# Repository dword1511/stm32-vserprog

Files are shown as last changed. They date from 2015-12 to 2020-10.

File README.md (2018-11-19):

# stm32-vserprog:
## flashrom serprog programmer based on STM32 MCU & USB CDC protocol.
**This project deprecates previous [`serprog-stm32vcp`](https://github.com/dword1511/serprog-stm32vcp) project,
  which uses STMicro's proprietary firmware library. Most functions are the same.**

* * *
### Features
* Fully open-source: now with [`libopencm3`](https://github.com/libopencm3/libopencm3) instead of STMicro's proprietary firmware library.
* Affordable and simple hardware:
  * An _STM32F103C8T6_ MCU, an 8MHz crystal, a 3.3V _1117_ LDO, some _0805_ capacitors, resistors and LEDs
    along with dedicated PCB available on OSH Park ([V2](https://oshpark.com/shared_projects/08Rj6sSm)
    or [V3](https://oshpark.com/shared_projects/vKn08YZG))
  * Or some general-purpose _STM32_ development boards,
  just add a new header file under "boards" folder to assign correct GPIO for USB D+ pull-up (_STM32F1_ only) and LEDs.
  * Hardware USB 2.0 Full-Speed and efficient virtual COM port with USB CDC protocol operates at any baud rates,
  eliminates the need of USB-to-UART bridges and the headache that comes with them.
  * **Ironically, you will still have to buy or borrow a USB-to-UART bridge (not RS-232 but TTL level) to program the programmer itself,**
  unless you are using an _STM32F0x2_ device (which has USB ISP capability) or boards with embedded _ST-Link_ (see @FabianInostroza's fork).
* Hardware full-duplex SPI with DMA, multiple clock speeds available (default at the one closest to but under 10MHz), _e.g._ on STM32F103 targets:
  * 36MHz
  * 18MHz
  * 9MHz *(Default)*
  * 4.5MHz
  * 2.25MHz
  * 1.125MHz
  * 562.5kHz
  * 281.25kHz
* 2 status LEDs (controlled with 1 GPIO):
  * Busy is lit during operation (inverse for boards with only one LED).
  * Different operations cause different patterns of blinking:
  mostly busy = reading, both on = writing, flashing alternatively = erasing.
  * Busy blinks alone if a hard fault or NMI is detected. Please unplug and replug the programmer.
  If the situation persists, please consider [opening a new ticket](https://github.com/dword1511/stm32-vserprog/issues).
* `flashrom` "serprog" protocol:
  * Operates on all major platforms (see [`flashrom` wiki](http://www.flashrom.org/Flashrom)).
  * Driver-free on Linux. On Windows may require ST's VCP driver
  (or just hack the `.inf` file of other CDC drivers, not confirmed).
* Firmware is interrupt-free except for low-level USB handling -- robust, easy to debug and modify.
* Fast:
  * Read speed up to 850KiB/s @ 36MHz SPI operation.
  * Dumps an _EN25Q64_ in 11 seconds and programs in 85 seconds (including `flashrom`'s calibration time).
  * Way faster than many commercial _CH341_-based USB programmers, especially for reading.
* Supports 25 and 26 series SPI flash chips.
  **45 series flash chips have different pinouts. Thus for the V2 PCB mentioned above, you will need an adapter.**

* * *
### Installation
1. Install `stm32flash` and the `gcc-arm-none-eabi` toolchain.

  On Debian, simply do the following:

   ```bash
   sudo apt-get install stm32flash gcc-arm-none-eabi
   ```
  
  NOTE: some systems may require installing `newlib` (_e.g._ `libnewlib-arm-none-eabi`) manually. See [#27](https://github.com/dword1511/stm32-vserprog/issues/27).

1. Clone and compile.

  Simply type (change the board name accordingly, for details see the header of the `Makefile` or just type `make`):

   ```bash
   git clone --recurse-submodules https://github.com/dword1511/stm32-vserprog.git
   make BOARD=stm32-vserprog-v2
   ```
1. Program.

  Connect the USB-to-UART bridge to your computer first. Then connect _TXD_ and _RXD_ lines to your _STM32_ board with wires.
  On V2 or V3 boards mentioned above, connect _BOOT0_ (labeled _BT0_ on boards) to the 3.3V output of the USB-to-UART bridge.
  For other boards, find the _BOOT0_ jumper or ISP switch, put it into high or enabled.
  On some boards, you will also need to ensure _BOOT1_ is pulled low.
  Then, connect your _STM32_ board to your computer via USB to power it up.
  Finally, type:

   ```bash
   make BOARD=stm32-vserprog-v2 flash-uart
   ```
1. Done!

  Throw the USB-to-UART bridge away and enjoy.
  Do not forget to pull _BOOT0_ low before resetting or replugging the board.

* * *
### Usage
The following assumes Linux platform, and that the programmer appears as `/dev/ttyACM0`.

1. To read a flash chip:
  * Connect a 25 type SPI Flash to the board's DIP-8 slot or according to the schematics.
  * Connect your board to your PC via USB.
  * Type:

   ```bash
   flashrom -p serprog:dev=/dev/ttyACM0:4000000 -r file-to-save.bin
   ```
  * Sometimes `flashrom` will ask you to choose a chip, add something like:

   ```bash
   -c SST25VF040B
   ```
   This is because sometimes different devices with distinct timing requirements can only be distinguished by the device code,
   however currently `flashrom` will not read it as it is not returned by the `RDID` command.
1. To erase a flash chip:
  * Erase is automatically done during writing. However, if you simply want an empty chip, you will need to erase manually.
  * Type:

   ```bash
   flashrom -p serprog:dev=/dev/ttyACM0:4000000 -E
   ```
  * For certain chips like _MX25L6445E_, the first pass could fail with some old `flashrom` version,
    but if you try a second pass, everything will be alright. Seems that the first block needs more delay to be erased.
  * Flash contents are verified to be empty automatically.
  * The whole process can take a few minutes.
1. To write a flash chip:
  * Type:

   ```bash
   flashrom -p serprog:dev=/dev/ttyACM0:4000000 -w file-to-load.bin
   ```
  * Flash chips are checked and blocks that are not empty are automatically erased.
  * Images are verified after writing automatically.
  * The whole process can take a few minutes.

* * *
### Problems?
1. If you encountered something like "`Error: Cannot open serial port: Device or resource busy`", please try to stop or remove `ModemManager`.
1. Check your wirings and `flashrom` version. Do not forget to power the flash chip itself if operating on a breadboard or prototype board.
1. If you are sure it is caused by bugs in the programmer's firmware,
   please [open a new ticket](https://github.com/dword1511/stm32-vserprog/issues) and provide details,
   _e.g._ the board you are using and `flashrom`'s output. I appreciate your feedback.

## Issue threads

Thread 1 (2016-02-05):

Which stm32 should I use

relax79, 2016-02-05:
Hello, i am work notebook repair bussiness and i am work with bios most time. I have a genius g540 programmer and is so slow. I am decide to build your programmer but i see first this page"https://github.com/dword1511/serprog-stm32vcp"  and you say STM32F103C8T6 48pin in readme but mcu is different in the schematic pdf STM32F103Rxxx an i am buy STM32F103R8T6, it is 64pin. I saw later this version of the programmer but same confusing happen to me again , you say STM32F103C8T6 but in the schematic mcu is STM32F103C(B)T6 . I am good electronic skill but i do not understand modern digital mcu's so much :) . I am download also prebuilt binaries from here "http://dword1511.info/dword/projects/serprog-stm32vcp/prebuilt/" My question is can i use STM32F103R8T6 and if i use which hex or bin  and schematic correct, and also missing in the first schematic xtal (i know 8mhz and 2x15 or 22pf) and a lot of parts value, correct uart pin points  . If i not use then which mcu can i buy ?
"http://www.direnc.net/STM32F103CBT6-MCU-32BIT-CORTEX-M3-72MHZ-LQFP-48,PR-23142.html"
"http://www.direnc.net/STM32F103C8T6-MCU-32BIT-CORTEX-M3-72MHZ-LQFP-48,PR-23141.html"
"http://www.direnc.net/STM32F103C8T6-Mini-Development-Board-ARDUINO,PR-22302.html"
"http://www.direnc.net/ARM-Cortex-M3-STM32F103C8T6-STM32-development-board,PR-15818.html"
I am so sorry for my English, i know messed up the spech. Thanks.

dword1511, 2016-02-05:
Thanks for pointing the error out, I did not notice it for years!
The difference between STM32F103Cxxx is just different amount of Flash and RAM available. Since STM32F103C8T6 has the least amount, firmware built for it should also run on others.
If you have a board at hand, please send the schematics to me so I can write the board.h for it and compile the firmware you will need.

relax79, 2016-02-05:
I am not have a board, only have STM32F103R8T6 mcu "http://urun.gittigidiyor.com/ev-elektronigi/st-stm32f103r8t6-200855568" (I just bought a new). If you say buy a new mcu or board please chose for me in the links in my previus message then i am bought new one, not problem if it is working properly. Thanks,regards.

relax79, 2016-02-05:
I am confuse first place because you say "just with minor modifications in the source code to assign correct GPIO for USB D+ pullup and LEDs." I thought editing requires different mcu's.like c8t6, cbt6, r8t6.

dword1511, 2016-02-05:
If you do not have a board and need one, then just go for the cheapest STM32F103 board. Any MCU in the series will work without problem.

If you do have the board to solder the MCU you have just bought, please refer to https://github.com/dword1511/stm32-vserprog/blob/master/pcb/v2/sch.pdf for correct connection. R2/R4 in this schematic is 20ohm or so, PB2 and BOOT0 just need some pull down, C4/C5 are 15 or 22pF, C1/C2/C3 0.1uF, C6/C9 10uF, C7/C10 0.1uF. R6 is a fuse. LED can be omitted if you wish. Then just use "make BOARD=stm32-vserprog-v2" to compile the firmware.

STM32F103 series are pin-to-pin compatible when the package is the same. When package is not same, the pinout is different, but firmware sees no difference in terms of pin name.

relax79, 2016-02-05:
I have to decide which one to buy then i am prepare everything, If i happen some trouble i will let you know.I am really thanks your kind support,answers and effort to build this good project.

Closed 2016-06-09.

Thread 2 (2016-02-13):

Compile error when building for stm32-tiny042-v1

graugans, 2016-02-13:
There is an issue when building for stm32-tiny042-v1 or any stm32f0x boards

```
$ make BOARD=stm32-tiny042-v1
ln -sfT "boards/stm32-tiny042-v1.h" board.h
arm-none-eabi-gcc -O3 -Wall -g -fno-common -ffunction-sections -fdata-sections -DSTM32F0 -mthumb -mcpu=cortex-m0 -msoft-float -Ilibopencm3/include/  -c vserprog.c -o vserprog.o
In file included from vserprog.c:14:0:
vserprog.c: In function 'handle_command':
spi.h:11:42: error: 'GPIO_SPI1_NSS' undeclared (first use in this function)
 #define SPI_SELECT()   gpio_clear(GPIOA, GPIO_SPI1_NSS)
                                          ^
vserprog.c:193:7: note: in expansion of macro 'SPI_SELECT'
       SPI_SELECT();
       ^
spi.h:11:42: note: each undeclared identifier is reported only once for each function it appears in
 #define SPI_SELECT()   gpio_clear(GPIOA, GPIO_SPI1_NSS)
```

dword1511, 2016-02-13:
Hi, support for STM32F0x2 is not completed yet. I will try to finish it when I have time.

graugans, 2016-02-13:
Thx, this would be really cool

dword1511, 2016-03-03:
Implemented and tested, ready for use. STM32F0 version seems to be ~70% slower than STM32F1 version. Whether it is due to clock or configuration is still unknown.

Closed 2016-03-03.

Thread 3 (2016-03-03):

Write HAL to handle different MCU

dword1511, 2016-03-03:
Currently there is a lot of macros everywhere. Need to abstract things up and put them together.

Kurnihil, 2016-03-11:
After this rewriting it would be possible to use your library (program?) with the NXP board "FRDM-KE06Z" (MKE06Z128VLK4 MCU)..?

dword1511, 2016-03-11:
I do not have the board, and it seems libopencm3 currently does not support this MCU, so I think it will not.

Closed 2017-05-23.

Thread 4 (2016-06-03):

LPC/FWH support?

Split7fire, 2016-06-03:
On old project page (https://github.com/dword1511/serprog-stm32vcp) it is said that "Support LPC / FWH flash via parallel programming. [WIP]" but that about stm32-vserprog? Does it support LPC/FWH at hte moment?

dword1511, 2016-06-03:
No. In the old version it was marked as work in progress (WIP) but I never had time to finish it.

Split7fire, 2016-06-03:
Thanks for fast response,
so, LPC/FWH support in that project is working anyway? (read/write)

dword1511, 2016-06-03:
Unfortunately it is not.

Split7fire, 2016-06-03:
ok, thanks for clarification, I think this issue can be closed now.

swiftgeek, 2023-01-15:
Relevant fork/derivative work:
https://github.com/wosk/stm32-vserprog-lpc

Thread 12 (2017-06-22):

Native 4-byte addressing

eswierk, 2017-06-22:
It would be nice to support larger-capacity SPI NOR flash chips like W25256FV and N25Q256A that require 4-byte addressing.

dword1511, 2017-06-22:
`flashrom` currently does not support 4-byte addressing as far as I known. There were [patches](https://mail.coreboot.org/pipermail/flashrom/2015-January/013168.html) proposed but they are probably unmerged.

eswierk, 2017-06-22:
I've managed to get a flashrom with those patches working well enough to program an N25Q256A using an FT232H module, but it's awfully slow.

https://github.com/skyportsystems/flashrom/commits/master

eswierk, 2017-07-03:
It is possible to program N25Q/MT25QL chips larger than 16 MB with the existing flashrom serprog, using only commands with 3-byte addresses, plus the extended address register for the 4th byte. See https://github.com/skyportsystems/flashrom/commit/db3ca240 for an example.

Other chips may require native 4-byte addressing, but I haven't encountered them so far.

dword1511, 2017-07-03:
With a proper patch for `flashrom`, any serprog should be able to handle 4-byte addressing. It is merely an SPI-to-USB bridge. It has no knowledge about the protocol. The commands with address parameters in serprog protocol are for parallel flash chips. The only limitation for serprog with SPI is that the size of each transaction (command or data) must be under 16MB.

eswierk, 2017-07-03:
Ah! Thanks for the clarification. I confirmed that programming an M25QL256 with flashrom serprog works with direct 4-byte address commands. See https://github.com/skyportsystems/flashrom/commit/d30fcd40 .

Closed 2017-07-03.

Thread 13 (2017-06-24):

Build is failing on xenial

Ntemis, 2017-06-24:
make --directory=lib/stm32/f1 SRCLIBDIR="/media/demetris/c4487cfd-d71a-441b-b83d-23d8ce19475d/stm32-vserprog/libopencm3/lib"
make[3]: Entering directory '/media/demetris/c4487cfd-d71a-441b-b83d-23d8ce19475d/stm32-vserprog/libopencm3/lib/stm32/f1'
  CC      i2c_common_v1.c
arm-none-eabi-gcc -Os -Wall -Wextra -Wimplicit-function-declaration -Wredundant-decls -Wmissing-prototypes -Wstrict-prototypes -Wundef -Wshadow -I../../../include -fno-common -mcpu=cortex-m3  -mthumb -Wstrict-prototypes -ffunction-sections -fdata-sections -MD -DSTM32F1 -ggdb3 -O3 -Wall -g -fno-common -ffunction-sections -fdata-sections -funit-at-a-time -fgcse-sm -fgcse-las -fgcse-after-reload -funswitch-loops -DSTM32F1 -mthumb -mcpu=cortex-m3 -msoft-float -mfix-cortex-m3-ldrd -Ilibopencm3/include/  -o i2c_common_v1.o -c ../common/i2c_common_v1.c
../common/i2c_common_v1.c: In function 'i2c_write7_v1':
../common/i2c_common_v1.c:485:2: error: 'for' loop initial declarations are only allowed in C99 or C11 mode
  for (size_t i = 0; i < n; i++) {
  ^
../common/i2c_common_v1.c:485:2: note: use option -std=c99, -std=gnu99, -std=c11 or -std=gnu11 to compile your code
../common/i2c_common_v1.c: In function 'i2c_read7_v1':
../common/i2c_common_v1.c:507:2: error: 'for' loop initial declarations are only allowed in C99 or C11 mode
  for (size_t i = 0; i < n; ++i) {
  ^
../../Makefile.include:44: recipe for target 'i2c_common_v1.o' failed
make[3]: *** [i2c_common_v1.o] Error 1
make[3]: Leaving directory '/media/demetris/c4487cfd-d71a-441b-b83d-23d8ce19475d/stm32-vserprog/libopencm3/lib/stm32/f1'
Makefile:63: recipe for target 'lib/stm32/f1' failed
make[2]: *** [lib/stm32/f1] Error 2
make[2]: Leaving directory '/media/demetris/c4487cfd-d71a-441b-b83d-23d8ce19475d/stm32-vserprog/libopencm3'
Makefile:102: recipe for target 'libopencm3/lib/libopencm3_stm32f1.a' failed
make[1]: *** [libopencm3/lib/libopencm3_stm32f1.a] Error 2
make[1]: Leaving directory '/media/demetris/c4487cfd-d71a-441b-b83d-23d8ce19475d/stm32-vserprog'
Makefile:51: recipe for target 'all' failed
make: *** [all] Error 2

dword1511, 2017-06-25:
Please try `make EXTRA_CFLAGS="-std=gnu99"`. Also please post the output of `arm-none-eabi-gcc -v`.

dword1511, 2017-06-26:
Confirmed that `make EXTRA_CFLAGS="-std=gnu99"` worked on Xenial. Now included in Makefile.

Closed 2017-06-26.

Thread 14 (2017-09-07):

C1 V3 board value?

raoul170, 2017-09-07:
what value has c1 ?

dword1511, 2017-09-07:
C1 is 0.1uF.

When I have time I will rectify all the schematics.

raoul170, 2017-09-07:
is it possible you make a release file? Want to program bin or hex via STlink , I cannot work with the makerfile thigs

Droid-MAX, 2019-04-21:
@raoul170 Look there: [STM32闪存编程器.zip](https://pan.droidmax.top/?/Programs/STM32%E9%97%AA%E5%AD%98%E7%BC%96%E7%A8%8B%E5%99%A8.zip)

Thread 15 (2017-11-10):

~~x�~hellowor problem

atesonur, 2017-11-10:
Thank you so much for your code, it helped me a lot. But I have a problem. When I start up my stm32f103 device and try to read 14 bytes from virtual port by using usb_getc(),  First 6 bytes are  always like ~~x�~ these. I understood that they stay there when I start up system and if I write 14 bytes,  I can only write first 8 bytes The first 6 bytes already occupied by these characters.
Do you have any suggestion and thanks a lot for the code you support.

dword1511, 2017-11-10:
Check whether there are other programs accessing the serial port.

atesonur, 2017-11-10:
Thank you so much for your time. None of my programs are using serial port and even I restarted my computer just in case. I am using linux and after restart,  I got these:

master@Lenovo:~/Desktop$ sudo python echo2.py helloworldonur
~~x�~hellowor
master@Lenovo:~/Desktop$ sudo python echo2.py helloworldonur
ldonurhellowor

Thank you so much.

dword1511, 2017-11-10:
I do not know what you are using. Can you use `minicom`?

Make sure `ModemManager` is not running.

atesonur, 2017-11-11:
Thank you so much. I used minicom. It is same but i used a similar command handler like you do. It works fine. Thanks a lot for your time.

dword1511, 2017-11-11:
Without the exact description of your code and what you are doing, I cannot help you. If it is a project of your own, please use email rather than issues. Thanks!

Closed 2017-11-11.

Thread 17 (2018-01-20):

Can build in window 7 ?

budiliauw87, 2018-01-20:
Hello dword, I'm very glad found your git from forum stm32ardunio.. i try complie in windows but failed.

Closed 2018-01-23.

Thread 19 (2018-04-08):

驱动这块会不会有问题？

Droid-MAX, 2018-04-08:
从打板到元器件采购到组装焊接再到编译烧录程序这整个流程都没有问题，但在Windows10/Linux系统的主机上使用时却无法正常识别出来，指示灯正常工作
PS：第一次插上去时在设备管理器中有个未知设备一闪而过，之后一点反应都没有
不知道是不是因为当时误把22千欧(片上标识为223)的贴片电阻用在R2和R4的缘故，不过现在已经换回来了
除此之外该排查的地方也都排查过了，仍未确定问题所在。。。

dword1511, 2018-04-10:
USB 1.5K 的上拉没有问题吗？Linux 下的 dmesg 看一下？确认 STM32 是原装正片？

Droid-MAX, 2018-04-10:
电阻片上标识为152，还没有量过

Droid-MAX, 2019-01-08:
问题已解决，原因在于按照README的操作步骤编译得来的是V2版本的固件，烧录到V3版本的板子里去的话是绝对有问题的，今天心血来潮又重新捡起了板子，修改了编译参数得到了V3版本固件，重新烧录到编程器当中，最终如愿以偿，非常感谢大佬的这个非常优秀的项目！

Closed 2019-01-08.

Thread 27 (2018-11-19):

Cosmic/18.04: Had to install libnewlib-arm-none-eabi to resolve stdint.h not found error.

kamilion, 2018-11-19:
Went and got stm32flash and gcc-arm-none-eabi on cosmic, but build failed. Googling indicated the package 'libnewlib-arm-none-eabi' was missing. Installed it. Build successful.

dword1511, 2018-11-19:
Thanks for the feedback. On most of the systems `gcc-arm-none-eabi` should depend on `newlib`. I will add a heads-up in the README.

Closed 2018-11-19.

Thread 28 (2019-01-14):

How to use udev rules to make a symbol link of /dev/ttyACM<N>

KalelCooper, 2019-01-14:
First  let's see how 'Black Magic Probe' did this:
```
$ udevadm info --attribute-walk /dev/ttyACM0
  looking at device '/devices/pci0000:00/0000:00:1a.1/usb4/4-1/4-1:1.0/tty/ttyACM0':
    KERNEL=="ttyACM0"
    SUBSYSTEM=="tty"
    DRIVER==""

  looking at parent device '/devices/pci0000:00/0000:00:1a.1/usb4/4-1/4-1:1.0':
    KERNELS=="4-1:1.0"
    SUBSYSTEMS=="usb"
    DRIVERS=="cdc_acm"
    ...
    ATTRS{interface}=="Black Magic GDB Server"
```
And it's udev rules like this:
```
DRIVERS=="cdc_acm", ATTRS{interface}=="Black Magic GDB Server", SYMLINK+="bmp_gdb"
DRIVERS=="cdc_acm", ATTRS{interface}=="Black Magic UART Port", SYMLINK+="bmp_uart"
```

But stm32-vserprog has no such thing like ATTRS{interface} :
```
$ udevadm info --attribute-walk /dev/ttyACM2
  looking at device '/devices/pci0000:00/0000:00:1d.2/usb8/8-2/8-2:1.0/tty/ttyACM2':
    KERNEL=="ttyACM2"
    SUBSYSTEM=="tty"
    DRIVER==""
  looking at parent device '/devices/pci0000:00/0000:00:1d.2/usb8/8-2/8-2:1.0':
    KERNELS=="8-2:1.0"
    SUBSYSTEMS=="usb"
    DRIVERS=="cdc_acm"
    ...
    ATTRS{supports_autosuspend}=="1"
```
So, how to add "ATTRS{interface}" to stm32-vserprog ?

dword1511, 2019-01-18:
Use `ATTR{ID_MODEL}=="STM32_virtual_serprog_for_flashrom"`. I did not specify strings for individual interfaces.

Closed 2020-06-11.

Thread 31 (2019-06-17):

How to connect a 25 type SPI Flash to the board's DIP-8 slot ? where can find the schematics?

liaolunhui, 2019-06-17:
I am new to MCU.
Can anyone show me schematics that connect STM32F103C8T6 and 8 pin flash ?
Thanks

dword1511, 2019-06-18:
See https://github.com/dword1511/stm32-vserprog/blob/master/pcb/v2/sch.pdf

Closed 2020-06-11.

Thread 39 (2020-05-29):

按照原理图做了一个V3的版本，测试25 SPI读取速度有点慢，不知道哪里出问题了

realgtk, 2020-05-29:
time flashrom -p serprog:dev=/dev/ttyACM0:4000000 -r dump.bin -c "MX25L6406E/MX25L6408E"
real	1m59.147s
user	0m1.864s
sys	0m0.075s
直接编译的，没有修改任何配置。
加上spispeed参数也没有效果。

realgtk, 2020-05-29:
查下来是虚拟机的问题，在实体机上没问题，速度飞快，感谢！！

Closed 2020-05-29.

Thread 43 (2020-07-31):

Unable to get past make BOARD=stm32-bluepill

ginL, 2020-07-31:
It seems I cannot get past this. Tried POP_OS and mint.

Here is a copy of the error code

```
mint@mint:~/stm32-vserprog$ sudo make BOARD=stm32-bluepill
First run, cleaning...
make[1]: Entering directory '/home/mint/stm32-vserprog'
rm -f vserprog.o usbcdc.o spi.o README.html stm32-vserprog.elf stm32-vserprog.hex stm32-vserprog.bin stm32-vserprog.map stm32-vserprog.out board.h last_board.mk
make[1]: Leaving directory '/home/mint/stm32-vserprog'
make[1]: Entering directory '/home/mint/stm32-vserprog'
git submodule init
git submodule update --init
CFLAGS="-O3 -Wall -g3 -gdwarf -std=gnu99 -fno-common -ffunction-sections -fdata-sections -funit-at-a-time -fgcse-sm -fgcse-las -fgcse-after-reload -funswitch-loops -DSTM32F1 -mthumb -mcpu=cortex-m3 -msoft-float -mfix-cortex-m3-ldrd -Ilibopencm3/include/ " make -C libopencm3 lib/stm32/f1 PREFIX=arm-none-eabi- V=1
make[2]: Entering directory '/home/mint/stm32-vserprog/libopencm3'
  GENHDR  include/libopencm3/stm32/f0/irq.json
./scripts/irq2nvic_h ./include/libopencm3/stm32/f0/irq.json;
/usr/bin/env: ‘python’: No such file or directory
make[2]: *** [Makefile:59: include/libopencm3/stm32/f0/irq.json.genhdr] Error 127
make[2]: Leaving directory '/home/mint/stm32-vserprog/libopencm3'
make[1]: *** [Makefile:116: libopencm3/lib/libopencm3_stm32f1.a] Error 2
make[1]: Leaving directory '/home/mint/stm32-vserprog'
make: *** [Makefile:64: all] Error 2
mint@mint:~/stm32-vserprog$

```

dword1511, 2020-08-01:
You need to install python.

Not sure if libopencm3 uses python3 now, will check.

dword1511, 2020-08-25:
libopencm3 is still using python2 as of now. Some distro no longer comes with python2 by default, you will need to install it manually.

Closed 2020-08-25.

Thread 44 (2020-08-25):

赞，blog.dword1511.info无法评论，只有在这里评论了，附带一些文件下载地址

jiuweiljp, 2020-08-25:
非常不错，用10多元钱的stm32做了一个一次成功。
测试环境win7_x64+VirtualBox（ubuntu 18.04_64）,使用USB xHCI模式。
为什么用xHCI 因为我测试过在其它项目中使用xHCI 模式比EHCI的通讯速度快不少。
测试芯片winbond 25Q32FVSIG （4MBye），下面的结果是多次测试取的平均值：
读：6.255秒 657KByte/s ,擦除 45.69s ，写50.10s 81.74KByte/s
（以上测试用的20030331的固件）.
1、在linux下的用的是flashrom1.2，自己静态编译的版本i386版本（我发现在ub 16.04下动态编译的版本在ub18.04下尽然不能用）就索性编译了一个i386的静态flashrom。下载地址：
http://lzdz.f3322.net:81/serprog-stm32vcp/flashrom1.2_i386_static.tar.gz
2、windows 下也测试成功了，但是安装那个stm vcp费了点功夫，看了帖子http://www.openedv.co/forum.php?mod=viewthread&tid=72803 才解决了stm vcp安装后驱动出现感叹号的问题。
下载地址：
http://lzdz.f3322.net:81/serprog-stm32vcp/stm_vcp_usb缺少的文件.zip
stm_vcp1.4下载地址：
http://lzdz.f3322.net:81/serprog-stm32vcp/stm_VCP_1.4.zip
stm_vcp1.5下载地址：
http://lzdz.f3322.net:81/serprog-stm32vcp/stm_vcp_1.5_en.stsw-stm32102.zip
当然不会少了flashrom（别人编译的，版本1.1）下载地址：
http://lzdz.f3322.net:81/serprog-stm32vcp/flashrom_win v1.1.zip
使用方法:
flashrom.exe -p serprog:dev=comX:115200,spispeed=36000000 -r nul
但是我不知道怎么在win7 下计算时间，谁有办法，望告知,谢谢

jiuweiljp, 2020-08-25:
费了点功夫编译了libglib，libudev，libpci，然后有了静态 x64版本的flashrom1.2，这个支持的接口就很多了，下载地址
http://lzdz.f3322.net:81/serprog-stm32vcp/flashrom1.2_x64_static.tar.gz

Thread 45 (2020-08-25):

几个问题，望回复

jiuweiljp, 2020-08-25:
花了10.8买了一个stm 的demo板
原理图：
http://lzdz.f3322.net:81/serprog-stm32vcp/STM32F103C8T6最小系统原理图.pdf
照片：
http://lzdz.f3322.net:81/serprog-stm32vcp/1.jpg
http://lzdz.f3322.net:81/serprog-stm32vcp/2.jpg
http://lzdz.f3322.net:81/serprog-stm32vcp/3.jpg
也不清楚这个stm32 F103C8T6的真假，反正我是看不出来。

（1）、编译使用：
make BOARD=stm32-vserprog-v2
make BOARD=stm32-vserprog-v3
生成的固件简单测试都能读写，不知道那个更匹配我的的这个板
USB D+(PA12)因这个板上有3.3v的接线端子，所以我直接焊了一个1.5k的1/4瓦的电阻上去了。

2、led的问题，修改配置
boards/stm32-vserprog-v2.h

/* org
#define BOARD_RCC_LED                RCC_GPIOA
#define BOARD_PORT_LED               GPIOA
#define BOARD_PIN_LED                GPIO0
*/
/* mod */
#define BOARD_RCC_LED                RCC_GPIOC
#define BOARD_PORT_LED               GPIOC
#define BOARD_PIN_LED                GPIO13
/* mod  end */
#define BOARD_LED_HIGH_IS_BUSY       true

然后连接在pc13上的led灯工作了
led状态我观察了下，有如下几种：
1、长亮（IDLE？）
2、频率大概一秒的闪烁（不知道什么状态）
3、读flash的时候快速闪烁（灭的占空比高）
4、擦除flash的时候快速闪烁（亮的占空比高）
5、写flash的时候基本不灭（仔细观察感觉亮的占空比更高）
望告知1-2的状态，另外不知道3-5的状态是否正确

（3）、我的这个demo板用了2个晶振，那个接PC14，PC15的晶振taobao的介绍说是爱普生的32768Hz的，不知道能不能利用它，让读写的速度更快些，谢谢

dword1511, 2020-08-25:
1. 两种固件的 USB pull-up 不一样。你用的这块板子没有 pull-up，我不清楚为何 USB 能正常工作 （STM32 内部的 pull-up 应该不够）。除此之外没有区别。V3 因为使用 PA13 作为 pull-up，SWD 会不可用。
2. 1 是 idle，2 应该是读取。具体跟 Flash 有关（站空比取决与每个命令所需的时间）。
3. 32k 晶振用于 RTC，这里用不到。

jiuweiljp, 2020-08-26:
感谢你抽出时间回复！

有没有办法在windows计算程序运行时间？

jiuweiljp, 2020-08-26:
我用万用表测量过，这个demo板在PA12与3.3V之间有电阻，阻值有4K多。
如果用20030331的固件，有时候插上USB会出现unknown的设备（win 7），但是刷stm32-vserprog项目编译的固件后没有发现上述现象。

jiuweiljp, 2020-08-31:
如果你什么也没干，IDLE灯如果闪烁（间隔大约1秒），哪就是你的usb 连接有问题，重新拔插一下吧。

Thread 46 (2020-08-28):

如果能用STM32F103vct6 将nand 和spi 都支持就好了

jiuweiljp, 2020-08-28:
有人用STM32F103vct6 做了nand的编程器
https://github.com/bbogush/nand_programmer
我觉得两个项目合并起来难度应该不大（都用的是STM32F103系列的MCU），共用一个固件，这个项目将mcu升到STM32F103vct6，然后将代码移植下就好了。刷写spi 用flashrom程序，刷写nand 用nando的程序

whitcloudfly, 2023-05-13:
nando的spi nand怎么搞

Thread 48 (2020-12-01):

support for REVELPROG IS board

orangecms, 2020-12-01:
The REVELPROG IS from https://www.reveltronics.com/en/products/revelprog-is-serial-memory-programmer-usb is also based on an STM32. This firmware could be ported to it and possibly extended for more features. The PCB seems quite simple. :)

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

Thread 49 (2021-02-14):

XTW2 flasher support

romanstingler, 2021-02-14:
I have a XTW100 and one XTW2.
Unlocked both via SWD and flashed the XTW100 board code.

The XTW100 works perfect but the XTW2 doesn't.

As far as I can tell the PA2 and PA3 are still the same for WP / HOLD.
VCC is connected to the AMS1117.
Ground is much better and connected to the board ground.
CS    -> PA4
DO    -> PA6
GND -> VSS
DI -> PA7 / PB0
CLK -> PA5

I have removed the lines

```
  gpio_set_mode(GPIOB, GPIO_MODE_OUTPUT_50_MHZ, GPIO_CNF_OUTPUT_PUSHPULL, GPIO1|GPIO2);
  gpio_clear(GPIOB, GPIO1|GPIO2);
  ```

but this doesn't work either.

I can build it, flash it.
But in flashrom  I only get to the point where it probes for the first chip
and than it just hangs.

```
blackout@Workstation ~ % sudo flashrom -p serprog:dev=/dev/ttyACM0:400000 -r h.bin -VVV
flashrom v1.2-85-gf4eeefd8 on Linux 5.10.15-arch1-1 (x86_64)
flashrom is free software, get the source code at https://flashrom.org

flashrom was built with libpci 3.7.0, GCC 10.1.0, little endian
Command line (5 args): flashrom -p serprog:dev=/dev/ttyACM0:400000 -r h.bin -VVV
Using clock_gettime for delay loops (clk_id: 1, resolution: 1ns).
Initializing serprog programmer
Using custom baud rate.
serprog: connected - attempting to synchronize
writecnt 8 wr_bytes 0
wrote 8 bytes
write successful
writecnt 1 wr_bytes 0
wrote 1 bytes
write successful
.readcnt 1 rd_bytes 0
read -1 bytes
readcnt 1 rd_bytes 0
read 1 bytes
readcnt 1 rd_bytes 0
read 1 bytes
writecnt 1 wr_bytes 0
wrote 1 bytes
write successful
readcnt 1 rd_bytes 0
read -1 bytes
readcnt 1 rd_bytes 0
read 1 bytes
readcnt 1 rd_bytes 0
read 1 bytes

serprog: Synchronized
serprog: Interface version ok.
serprog: Bus support: parallel=off, LPC=off, FWH=off, SPI=on
Warning: Automatic command availability check failed for cmd 0x08 - won't execute cmd
Warning: Automatic command availability check failed for cmd 0x11 - won't execute cmd
serprog: Programmer name is "stm32-vserprog"
serprog: Serial buffer size is 65535
serprog: Output drivers enabled
The following protocols are supported: SPI.
Probing for AMIC A25L010, 128 kB: programmer_map_flash_region: mapping A25L010 from 0x00000000fffe0000 to 0x00000000fffe0000
serprog_spi_send_command, writecnt=1, readcnt=3
```

I would be thankful for any hints.

Thanks in advance

Schuby, 2021-06-17:
I have the same XTW2 with the GD32F103 and I'm getting the same issues as you. From what I can find online about the GD32F103 I think this might be an issue with libopencm3 rather than vserprog.

On my board, the power LED is connected directly to the ASM1117 and doesn't need any code from the xtw100 to make it work.

neg2led, 2021-08-15:
So the GD32F103 is a bit _weird_ when it comes to clock setup, and neither the stock STM32 clock config nor the GD32F103 one that's present in the code in master actually works properly, as best I can tell. Have to set the clock to 96MHz and do some other weird stuff to make USB work 100% right & get the APB2 clock set to the correct speed.

I've patched that up a bit (based on reading the latest datasheet from [here](http://www.gd32mcu.com/en/download/0?kw=GD32F1) and staring at the example code, plus [this helpful blog post](http://smdprutser.nl/blog/stm32f103-vs-gd32f103-round-4-spi-master/) and [its associated github repo](https://github.com/smdprutser/GD32Challenge/blob/master/source/SPI-master/SPI.c)) and you'll find that in [my fork over here](https://github.com/neg2led/stm32-vserprog)

I fired up debugging via Cortex Debug and an ST-Link v2 clone adapter, and regardless of whether the legacy code or the DMA code gets used for SPI transfers, sends work fine but receives all hang waiting for the SPI_SR_RXNE bit to clear (or the DMA 'transfer complete' interrupt to fire)

I don't have enough of a clue about how this whole deal works to actually debug it, but if anyone's got ideas i'm all-ears. Apparently the code in the github repo I mentioned above works just fine for doing SPI transmits and receives - even at 54MHz SPI clock 😮 - so it must be something to do with the full-duplex-mode setup, possibly software slave control issues?

neg2led, 2021-08-18:
I take it back, I do apparently have some clue about how this whole deal works 😝

So the problem is twofold; clock configuration on one end, and the GD32F103 absolutely _refusing_ to work with software slave select, at least with the way this firmware implements it. It throws a CONFERR no matter how I try to tweak things and just refuses to play ball.

If, however, I turn _off_ software slave select, it works just fine, even at (what should be) 48MHz SPI clock.

Benchmark with the old CPU copying routine:

```
Detecting flash...
Generating test file...
Erasing...
Verifying... PASS
Writing...
Reading...
Comparing...PASS

Flash type: MX25L6406E/MX25L6408E
Flash size: 8192 KiB
SPI speed : 50000000 Hz (requested)
Probe     :   1.00s
Erase     : 170.66s
Write     : 207.30s
Read      :  83.53s
```

And with DMA enabled:

```
Detecting flash...
Generating test file...
Erasing...
Verifying... PASS
Writing...
Reading...
Comparing...PASS

Flash type: MX25L6406E/MX25L6408E
Flash size: 8192 KiB
SPI speed : 50000000 Hz (requested)
Probe     :   1.00s
Erase     : 101.66s
Write     :  60.43s
Read      :  10.78s
```

So that's nice. What's the downside of using hardware NSS control? Seems like it should be fine to me?

Anyway, I've pushed the functional (as far as I can tell) code to [my fork over here](https://github.com/neg2led/stm32-vserprog) - clone and `make BOARD=xtw2` should do it. Will try to clean the commits up and maybe submit a PR soon :)

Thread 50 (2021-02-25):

关于针对W25Q256FV的4Byte地址模式的支持

Droid-MAX, 2021-02-25:
...

Droid-MAX, 2021-02-25:
https://github.com/dword1511/stm32-vserprog/issues/12

dword1511, 2021-02-25:
QSPI 跟 4-byte address 是两回事。4-byte address 用于支持 32M 和更大的闪存。

QSPI 有四根数据线。大部分 STM32 不支持这种接口。新一点的 F4 有支持。不过意义不大，因为 USB 2.0 FS 跑不了那么快，除非加上 HS PHY 。

Droid-MAX, 2021-02-26:
那如果想解决4-byte地址模式这个问题的话是不是还是得从上位机入手？比如修改flashrom的源码？

dword1511, 2021-02-26:
最新的 flashrom 应该已经支持 4BA 了
https://www.flashrom.org/Flashrom/1.1

Droid-MAX, 2021-03-01:
我知道问题所在了！
对于Winbond W25Q256FV闪存芯片来说，flashrom确实已经支持4Byte地址模式操作，不过决定闪存工作在3Byte/4Byte地址模式的ADP寄存器状态并未被设置为4Byte地址模式，所以导致系统无法正常启动的问题。同时我也找到了一个针对W25Q256FV的ADP寄存器状态设置的修改版flashrom，不过还没测试，希望可以解决我这问题。
https://github.com/huming2207/flashrom_google
我也给编译到了Windows平台上
https://github.com/Droid-MAX/flashrom_mod/releases/tag/1.0

Droid-MAX, 2021-03-02:
已结案，故close该issue.

Closed 2021-03-02.

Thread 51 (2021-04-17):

flashrom Git URL needs updating

onetransistor, 2021-04-17:
I tried to pull and compile this repo and it fails because of flashrom. The [Git URL of flashrom submodule](https://github.com/dword1511/stm32-vserprog/blob/master/.gitmodules) should be updated from:

```
[submodule "flashrom"]
	path = flashrom
	url = https://www.flashrom.org/git/flashrom.git
	branch = staging
```

to:

```
[submodule "flashrom"]
	path = flashrom
	url = https://github.com/flashrom/flashrom.git
	branch = master
```

It would then compile without errors.

dword1511, 2021-04-18:
Fixed by #52

Closed 2021-04-18.

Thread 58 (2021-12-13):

stm32-bluepill failed to init device

CoderBasis, 2021-12-13:
Hi,
I am trying to install this on my stm32-bluepill via a CJMCU-FT232H, but I just get "failed to init device". I am new to this and I am not completely sure what is going on. I think my wiring is correct, and I specified "BOARD=stm32-bluepill" in the make program. Would you mind helping me figure this out?

utherbone, 2022-05-01:
Try https://github.com/dword1511/stm32-vserprog/issues/43
Can have with that, try it, I use ftdi FT232RL

dword1511, 2022-05-03:
Most likely an issue with the UART connection, or counterfeit STM32 chips.

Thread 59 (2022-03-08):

Works fine on MacOS (M1 Mac)

n8henrie, 2022-03-08:
Hello -- thanks for a great project!

I just wanted to note for other readers searching the issues that this worked *fine* on my M1 Mac running MacOS 12.2.1 just by downloading `gcc-arm-none-eabi` and adding it to my `$PATH`.

If you're interested in incorporating this into the README, I'd be more than happy to refactor this into a PR! If not please close the issue, no worries.

My process:

1. On STM32: move jumper closer to the edge from 0->1
1. Put FTDI at 3.3v
1. Connect the (unplugged) FTDI to the STM32 (remember: **T**x goes to **T**en)

FTDI|STM32
---|---
TX|A10
RX|A9
3V|3V
GND|GND

```bash
export SERIAL=/dev/tty.usbserial-00000000 # or whatever the device is in your case

wget 'https://developer.arm.com/-/media/Files/downloads/gnu-rm/10.3-2021.10/gcc-arm-none-eabi-10.3-2021.10-mac.tar.bz2'
tar -xjf gcc-arm-none-eabi-10.3-2021.10-mac.tar.bz2
PATH+=:"$(pwd)"/gcc-arm-none-eabi-10.3-2021.10/bin
export PATH

git submodule add https://github.com/dword1511/stm32-vserprog.git`
git submodule update --init --recursive`
cd stm32-vserprog/
make BOARD=stm32-vserprog-v2
make BOARD=stm32-vserprog-v2 flash-uart
```

```console
$ flashrom -p serprog:dev="${SERIAL}"
... works fine
```

I was adding this to an existing git project, so instead of the `submodule` business above, most users will probably want to use `git clone --recurse-submodules` as per the README.

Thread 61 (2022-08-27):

MT25QL512

neur0ner25, 2022-08-27:
Hello.
I tried to flash MT25QL512 chip with rp pico serprog from this git https://github.com/kazigk/pico-serprog
What is the problem? Same problem on xtw100
[log_pico_serprog_MT25QL512.txt](https://github.com/dword1511/stm32-vserprog/files/9438204/log_pico_serprog_MT25QL512.txt)

neur0ner25, 2022-08-27:
Ch341a and dediprog work well with this chip

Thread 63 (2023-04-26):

Nucleo F411RE: more than header config?

sebek0F9, 2023-04-26:
Im guessing the nucleo board stm32f411RE is a bit different with pinouts, and I would have to configure more than just a header file in boards/ , right?

I would have to modify stm32/common/gpio_f24.h? Or, do I use the letter groups to update a new file, naming it in boards/nucleo_blackpill.h?

sebek0F9, 2023-04-26:
PA_5: LED , spi1_SCLK
PA_15: SPI1_SSEL
PA_6: SPI1_MISO
PA_7:SPI1_MOSI

Stredoslovak, 2024-09-23:
Hello, have you managed to figure it out?
If so, were you successful in using the Blackpill as a flash programmer, with this repo?

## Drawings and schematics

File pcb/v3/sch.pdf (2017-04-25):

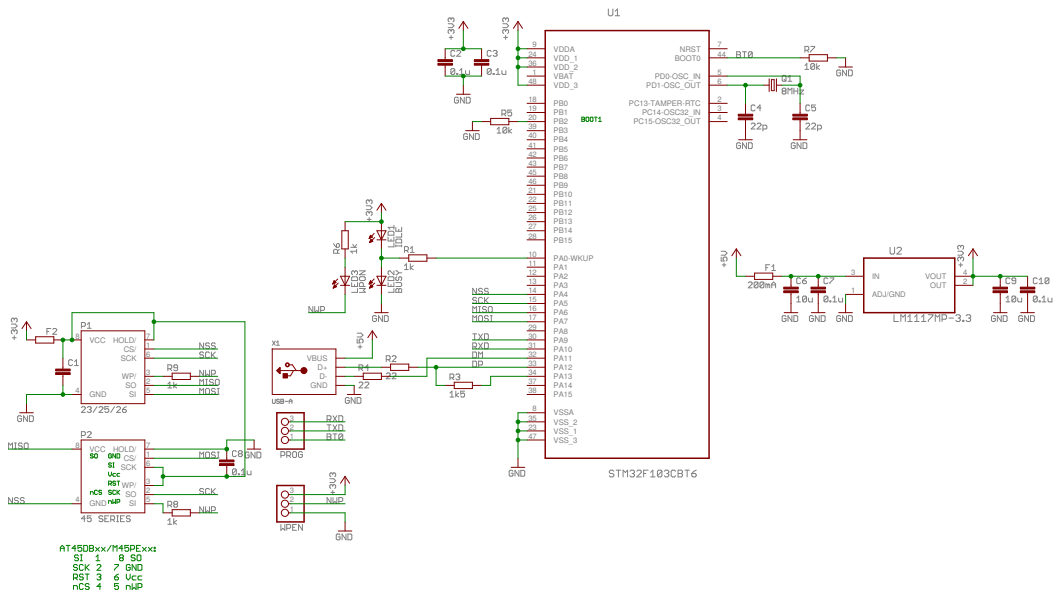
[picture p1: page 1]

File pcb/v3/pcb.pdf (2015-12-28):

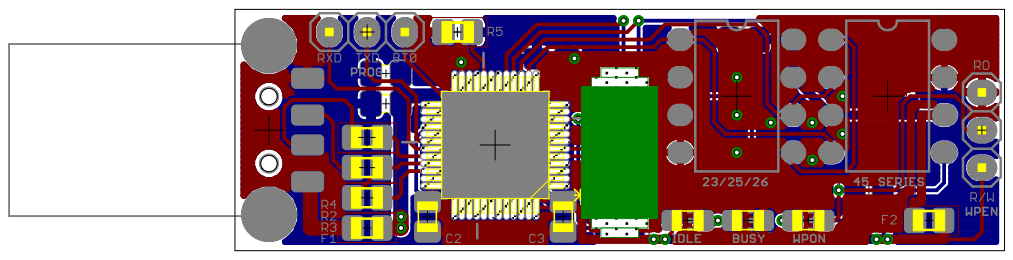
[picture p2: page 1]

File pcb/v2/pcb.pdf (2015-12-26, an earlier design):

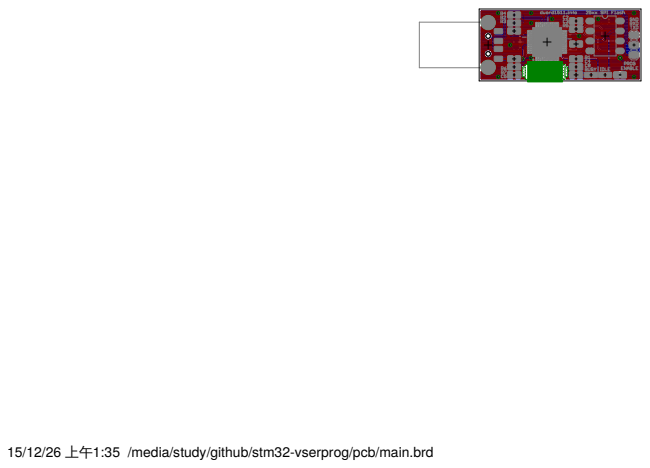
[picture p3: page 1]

15/12/26 上午1:35 /media/study/github/stm32-vserprog/pcb/main.brd

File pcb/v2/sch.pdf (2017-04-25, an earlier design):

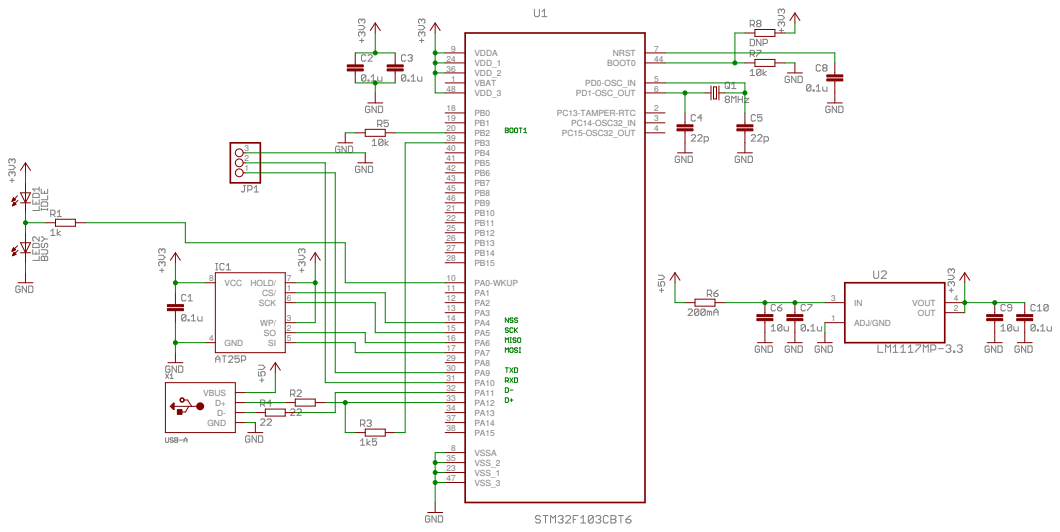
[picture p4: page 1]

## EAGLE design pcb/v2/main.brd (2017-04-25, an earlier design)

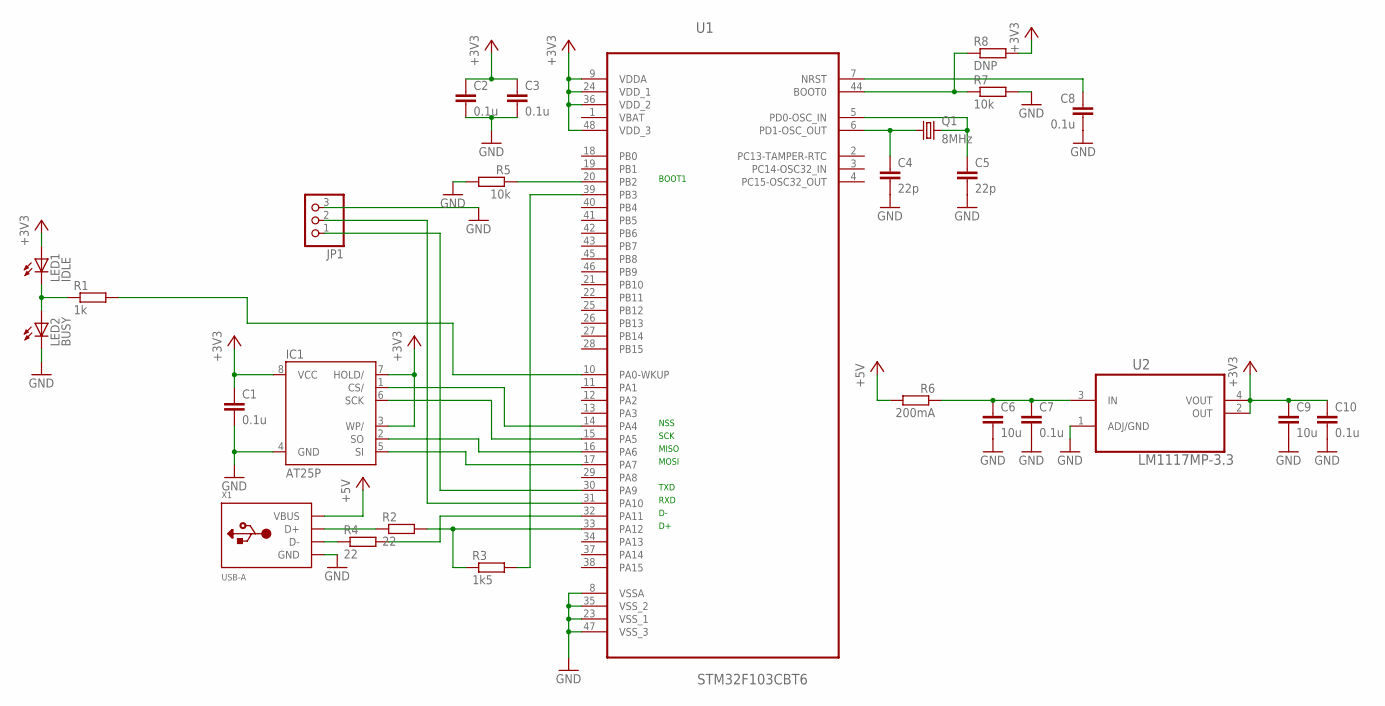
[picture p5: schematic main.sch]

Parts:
C1, C2, C3, C7, C8, C10: 0.1u; C0805K
C4, C5: 22p; C0805K
C6, C9: 10u; C0805K
IC1: AT25P; DIL08
JP1: PINHD-1X3; 1X03
LED1: IDLE; CHIP-LED0805
LED2: BUSY; CHIP-LED0805
Q1: 8MHz; HC49/S
R1: 1k; R0805
R2, R4: 22; R0805
R3: 1k5; R0805
R5, R7: 10k; R0805
R6: 200mA; R0805
R8: DNP; R0805
U1: STM32F103CBT6; QFP50P900X900X160-48N
U2: LM1117MP-3.3; SOT230P696X180-4N
X1: USB-A; MOLEX_480371000

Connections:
+3V3: C1.1, C2.1, C3.1, C9.1, C10.1, IC1.3 (WP/), IC1.7 (HOLD/), IC1.8 (VCC), LED1.A, R8.2, U1.9 (VDDA), U1.24 (VDD_1), U1.36 (VDD_2), U1.48 (VDD_3), U2.2 (OUT), U2.4 (VOUT)
+5V: R6.2, X1.1 (VBUS)
GND: C1.2, C2.2, C3.2, C4.2, C5.2, C6.2, C7.2, C8.2, C9.2, C10.2, IC1.4 (GND), JP1.3, LED2.C, R5.2, R7.2, U1.8 (VSSA), U1.23 (VSS_1), U1.35 (VSS_2), U1.47 (VSS_3), U2.1 (ADJ/GND), X1.4 (GND)
unnamed: C5.1, Q1.2, U1.5 (PD0-OSC_IN)
unnamed: C4.1, Q1.1, U1.6 (PD1-OSC_OUT)
unnamed: R5.1, U1.20 (PB2)
unnamed: R4.2, U1.32 (PA11)
unnamed: C8.1, U1.7 (NRST)
unnamed: R3.2, U1.39 (PB3)
unnamed: C6.1, C7.1, R6.1, U2.3 (IN)
unnamed: JP1.2, U1.31 (PA10)
unnamed: R7.1, R8.1, U1.44 (BOOT0)
unnamed: IC1.1 (CS/), U1.14 (PA4)
unnamed: IC1.6 (SCK), U1.15 (PA5)
unnamed: IC1.2 (SO), U1.16 (PA6)
unnamed: IC1.5 (SI), U1.17 (PA7)
unnamed: LED1.C, LED2.A, R1.1
unnamed: JP1.1, U1.30 (PA9)
unnamed: R4.1, X1.2 (D-)
unnamed: R2.1, X1.3 (D+)
unnamed: R1.2, U1.10 (PA0-WKUP)
unnamed: R2.2, R3.1, U1.33 (PA12)

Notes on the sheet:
TXD
RXD
BOOT1
NSS
SCK
MISO
MOSI

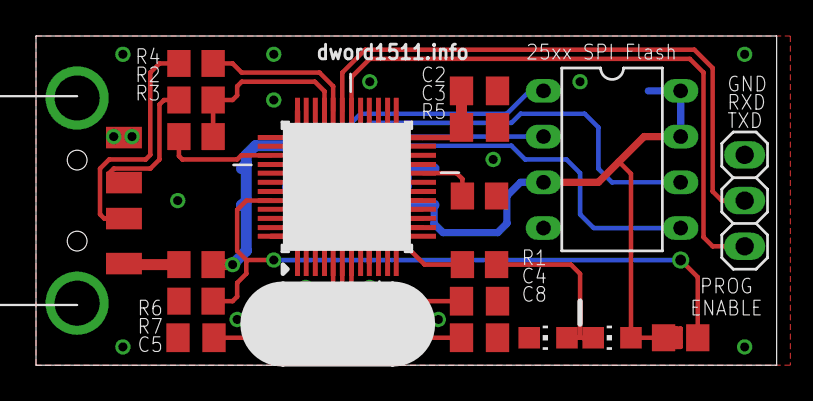
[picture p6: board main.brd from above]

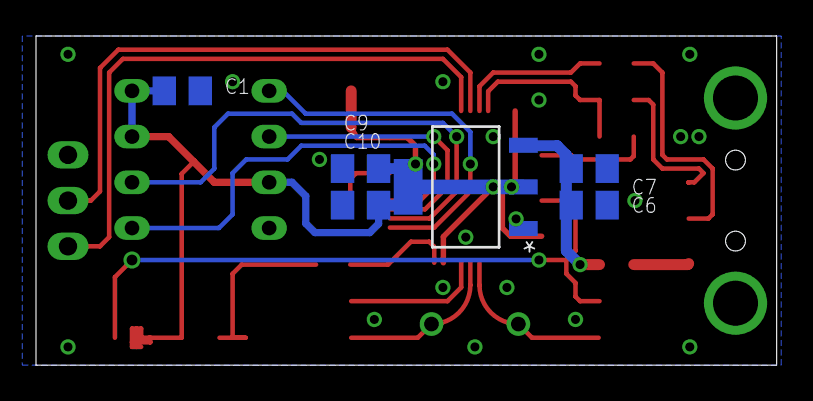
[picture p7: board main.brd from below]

Board: 2 copper layers, 41.1 x 18.3 mm, 26 parts (6 on the bottom side), 22 nets.

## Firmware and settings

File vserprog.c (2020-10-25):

#include <stdbool.h>

#include <libopencm3/stm32/rcc.h>
#include <libopencm3/stm32/gpio.h>
#include <libopencm3/cm3/nvic.h>
#include <libopencm3/usb/usbd.h>
#ifdef STM32F0
#include <libopencm3/stm32/crs.h>
#include <libopencm3/stm32/syscfg.h>
#endif /* STM32F0 */

#include "flashrom/serprog.h"
#include "flashrom/flash.h" /* For bus type */

#include "board.h"
#include "usbcdc.h"
#include "spi.h"

#define S_IFACE_VERSION   0x01             /* Currently version 1 */
#define S_PGM_NAME        "stm32-vserprog" /* The program's name, must < 16 bytes */
#define S_SUPPORTED_BUS   BUS_SPI
#define S_CMD_MAP ( \
  (1 << S_CMD_NOP)       | \
  (1 << S_CMD_Q_IFACE)   | \
  (1 << S_CMD_Q_CMDMAP)  | \
  (1 << S_CMD_Q_PGMNAME) | \
  (1 << S_CMD_Q_SERBUF)  | \
  (1 << S_CMD_Q_BUSTYPE) | \
  (1 << S_CMD_SYNCNOP)   | \
  (1 << S_CMD_O_SPIOP)   | \
  (1 << S_CMD_S_BUSTYPE) | \
  (1 << S_CMD_S_SPI_FREQ)| \
  (1 << S_CMD_S_PIN_STATE) \
)

#ifdef STM32F0
#define LED_ENABLE()  { \
  gpio_mode_setup(BOARD_PORT_LED, GPIO_MODE_OUTPUT, GPIO_PUPD_NONE, BOARD_PIN_LED); \
  gpio_set_output_options(BOARD_PORT_LED, GPIO_OTYPE_PP, GPIO_OSPEED_LOW, BOARD_PIN_LED); \
}
#define LED_DISABLE() gpio_mode_setup(BOARD_PORT_LED, GPIO_MODE_INPUT, GPIO_PUPD_NONE, BOARD_PIN_LED);
#else
#define LED_ENABLE()  gpio_set_mode(BOARD_PORT_LED, GPIO_MODE_OUTPUT_2_MHZ, GPIO_CNF_OUTPUT_PUSHPULL, BOARD_PIN_LED)
#define LED_DISABLE() gpio_set_mode(BOARD_PORT_LED, GPIO_MODE_INPUT, GPIO_CNF_INPUT_FLOAT, BOARD_PIN_LED)
#endif /* STM32F0 */

#if BOARD_LED_HIGH_IS_BUSY
#define LED_BUSY()    gpio_set(BOARD_PORT_LED, BOARD_PIN_LED)
#define LED_IDLE()    gpio_clear(BOARD_PORT_LED, BOARD_PIN_LED)
#else
#define LED_BUSY()    gpio_clear(BOARD_PORT_LED, BOARD_PIN_LED)
#define LED_IDLE()    gpio_set(BOARD_PORT_LED, BOARD_PIN_LED)
#endif /* BOARD_LED_HIGH_IS_BUSY */

void handle_command(unsigned char command) {
  static uint8_t   i;        /* Loop                */
  static uint8_t   l;        /* Length              */
  static uint32_t  slen;     /* SPIOP write length  */
  static uint32_t  rlen;     /* SPIOP read length   */
  static uint32_t  freq_req; /* Requested SPI clock */

  LED_BUSY();

  switch(command) {
    case S_CMD_NOP: {
      usbcdc_putc(S_ACK);
      break;
    }

    case S_CMD_Q_IFACE: {
      // TODO: use usbcdc_write for better efficiency
      usbcdc_putc(S_ACK);

      /* little endian multibyte value to complete to 16bit */
      usbcdc_putc(S_IFACE_VERSION);
      usbcdc_putc(0);

      break;
    }

    case S_CMD_Q_CMDMAP: {
      // TODO: use usbcdc_write for better efficiency
      usbcdc_putc(S_ACK);

      /* little endian */
      usbcdc_putu32(S_CMD_MAP);

      for(i = 0; i < 32 - sizeof(uint32_t); i++) {
        usbcdc_putc(0);
      }

      break;
    }

    case S_CMD_Q_PGMNAME: {
      // TODO: use usbcdc_write for better efficiency
      usbcdc_putc(S_ACK);

      l = 0;
      while(S_PGM_NAME[l]) {
        usbcdc_putc(S_PGM_NAME[l]);
        l ++;
      }

      for(i = l; i < 16; i++) {
        usbcdc_putc(0);
      }

      break;
    }

    case S_CMD_Q_SERBUF: {
      // TODO: use usbcdc_write for better efficiency
      usbcdc_putc(S_ACK);

      /* Pretend to be 64K (0xffff) */
      usbcdc_putc(0xff);
      usbcdc_putc(0xff);

      break;
    }

    case S_CMD_Q_BUSTYPE: {
      // TODO: use usbcdc_write for better efficiency
      // TODO: LPC / FWH IO support via PP-Mode
      usbcdc_putc(S_ACK);
      usbcdc_putc(S_SUPPORTED_BUS);

      break;
    }

    case S_CMD_Q_CHIPSIZE: {
      break;
    }

    case S_CMD_Q_OPBUF: {
      // TODO: opbuf function 0
      break;
    }

    case S_CMD_Q_WRNMAXLEN: {
      break;
    }

    case S_CMD_R_BYTE: {
      break;
    }

    case S_CMD_R_NBYTES: {
      break;
    }

    case S_CMD_O_INIT: {
      break;
    }

    case S_CMD_O_WRITEB: {
      // TODO: opbuf function 1
      break;
    }

    case S_CMD_O_WRITEN: {
      // TODO: opbuf function 2
      break;
    }

    case S_CMD_O_DELAY: {
      // TODO: opbuf function 3
      break;
    }

    case S_CMD_O_EXEC: {
      // TODO: opbuf function 4
      break;
    }

    case S_CMD_SYNCNOP: {
      // TODO: use usbcdc_write for better efficiency
      usbcdc_putc(S_NAK);
      usbcdc_putc(S_ACK);

      break;
    }

    case S_CMD_Q_RDNMAXLEN: {
      // TODO
      break;
    }

    case S_CMD_S_BUSTYPE: {
      /* We do not have multiplexed bus interfaces,
       * so simply ack on supported types, no setup needed. */
      if((usbcdc_getc() | S_SUPPORTED_BUS) == S_SUPPORTED_BUS) {
        usbcdc_putc(S_ACK);
      } else {
        usbcdc_putc(S_NAK);
      }

      break;
    }

    case S_CMD_O_SPIOP: {
      slen = usbcdc_getu24();
      rlen = usbcdc_getu24();

      SPI_SELECT();

      /* TODO: handle errors with S_NAK */
      if(slen) {
        spi_bulk_write(slen);
      }
      usbcdc_putc(S_ACK); // TODO: S_ACK early for better performance (so while DMA is working, programmer can receive next command)?
      if(rlen) {
        spi_bulk_read(rlen); // TODO: buffer?
      }

      SPI_UNSELECT();
      break;
    }

    case S_CMD_S_SPI_FREQ: {
      freq_req = usbcdc_getu32();

      if(freq_req == 0) {
        usbcdc_putc(S_NAK);
      } else {
        usbcdc_putc(S_ACK);
        usbcdc_putu32(spi_setup(freq_req));
      }

      break;
    }

    case S_CMD_S_PIN_STATE: {
      if( usbcdc_getc() )
          spi_enable_pins();
      else
          spi_disable_pins();
      usbcdc_putc(S_ACK);
      break;
    }

    default: {
      break; // TODO: notify protocol failure malformed command
    }
  }

  LED_IDLE();
}

#ifdef GD32F103
#define  RCC_GCFGR_ADCPS_DIV12  ((uint32_t)0x10004000)
#define  RCC_GCFGR_ADCPS_DIV16  ((uint32_t)0x1000C000)
#define  RCC_GCFGR_USBPS_Div2_5 ((uint32_t)0x00800000)
#define  RCC_GCFGR_USBPS_Div2   ((uint32_t)0x00C00000)

static void rcc_clock_setup_in_hse_12mhz_out_96mhz(void) {
  /* Enable internal high-speed oscillator. */
  rcc_osc_on(RCC_HSI);
  rcc_wait_for_osc_ready(RCC_HSI);

  /* Select HSI as SYSCLK source. */
  rcc_set_sysclk_source(RCC_CFGR_SW_SYSCLKSEL_HSICLK);

  /* Enable external high-speed oscillator 12MHz. */
  rcc_osc_on(RCC_HSE);
  rcc_wait_for_osc_ready(RCC_HSE);
  rcc_set_sysclk_source(RCC_CFGR_SW_SYSCLKSEL_HSECLK);

  /*
   * Set prescalers for AHB, ADC, ABP1, ABP2.
   * Do this before touching the PLL
   */
  rcc_set_hpre(RCC_CFGR_HPRE_SYSCLK_NODIV);   /* Set. 96MHz Max. 108MHz */
  rcc_set_adcpre(RCC_CFGR_ADCPRE_PCLK2_DIV8); /* Set. 12MHz Max. 14MHz  */
  rcc_set_ppre1(RCC_CFGR_PPRE1_HCLK_DIV2);    /* Set. 48MHz Max. 54MHz  */
  rcc_set_ppre2(RCC_CFGR_PPRE2_HCLK_NODIV);   /* Set. 96MHz Max. 108MHz */
  RCC_CFGR |= RCC_GCFGR_USBPS_Div2;           /* USB Set. 48MHz  Max. 48MHz  */

  /* GD32 has 0-wait-state flash, do not touch anything! */

  /*
   * Set the PLL multiplication factor to 8.
   * 12MHz (external) * 8 (multiplier) = 96MHz
   */
  rcc_set_pll_multiplication_factor(RCC_CFGR_PLLMUL_PLL_CLK_MUL8);

  /* Select HSE as PLL source. */
  rcc_set_pll_source(RCC_CFGR_PLLSRC_HSE_CLK);

  /*
   * External frequency undivided before entering PLL
   * (only valid/needed for HSE).
   */
  rcc_set_pllxtpre(RCC_CFGR_PLLXTPRE_HSE_CLK);

  /* Enable PLL oscillator and wait for it to stabilize. */
  rcc_osc_on(RCC_PLL);
  rcc_wait_for_osc_ready(RCC_PLL);

  /* Select PLL as SYSCLK source. */
  rcc_set_sysclk_source(RCC_CFGR_SW_SYSCLKSEL_PLLCLK);

  /* Set the peripheral clock frequencies used */
  rcc_ahb_frequency  = 96000000;
  rcc_apb1_frequency = 48000000;
  rcc_apb2_frequency = 96000000;
}

static void rcc_clock_setup_in_hse_12mhz_out_120mhz(void) {
  /* Enable internal high-speed oscillator. */
  rcc_osc_on(RCC_HSI);
  rcc_wait_for_osc_ready(RCC_HSI);

  /* Select HSI as SYSCLK source. */
  rcc_set_sysclk_source(RCC_CFGR_SW_SYSCLKSEL_HSICLK);

  /* Enable external high-speed oscillator 12MHz. */
  rcc_osc_on(RCC_HSE);
  rcc_wait_for_osc_ready(RCC_HSE);
  rcc_set_sysclk_source(RCC_CFGR_SW_SYSCLKSEL_HSECLK);

  /*
   * Set prescalers for AHB, ADC, ABP1, ABP2.
   * Do this before touching the PLL
   */
  rcc_set_hpre(RCC_CFGR_HPRE_SYSCLK_NODIV);      /* Set. 120MHz Max. 108MHz */
  RCC_CFGR = (RCC_CFGR & ~RCC_CFGR_ADCPRE) | RCC_GCFGR_ADCPS_DIV12; /* ADC Set. 10MHz  Max. 14MHz  */
  rcc_set_ppre1(RCC_CFGR_PPRE1_HCLK_DIV2);       /* Set. 60MHz  Max. 54MHz  */
  rcc_set_ppre2(RCC_CFGR_PPRE2_HCLK_NODIV);      /* Set. 120MHz Max. 108MHz */
  RCC_CFGR |= RCC_GCFGR_USBPS_Div2_5;            /* USB Set. 48MHz  Max. 48MHz  */

  /* GD32 has 0-wait-state flash, do not touch anything! */

  /*
   * Set the PLL multiplication factor to 10.
   * 12MHz (external) * 10 (multiplier) = 120MHz
   */
  rcc_set_pll_multiplication_factor(RCC_CFGR_PLLMUL_PLL_CLK_MUL10);

  /* Select HSE as PLL source. */
  rcc_set_pll_source(RCC_CFGR_PLLSRC_HSE_CLK);

  /*
   * External frequency undivided before entering PLL
   * (only valid/needed for HSE).
   */
  rcc_set_pllxtpre(RCC_CFGR_PLLXTPRE_HSE_CLK);

  /* Enable PLL oscillator and wait for it to stabilize. */
  rcc_osc_on(RCC_PLL);
  rcc_wait_for_osc_ready(RCC_PLL);

  /* Select PLL as SYSCLK source. */
  rcc_set_sysclk_source(RCC_CFGR_SW_SYSCLKSEL_PLLCLK);

  /* Set the peripheral clock frequencies used */
  rcc_ahb_frequency  = 120000000;
  rcc_apb1_frequency = 60000000;
  rcc_apb2_frequency = 120000000;
}
#endif /* GD32F103 */

int main(void) {
  uint32_t i;

  rcc_periph_clock_enable(BOARD_RCC_LED);
  LED_ENABLE();
  LED_BUSY();

/* Setup clock accordingly */
#ifdef GD32F103
  rcc_clock_setup_in_hse_12mhz_out_120mhz();
#else
#ifdef STM32F0
  rcc_clock_setup_in_hsi48_out_48mhz();
  rcc_periph_clock_enable(RCC_SYSCFG_COMP);
  SYSCFG_CFGR1 |= SYSCFG_CFGR1_PA11_PA12_RMP;
  rcc_periph_clock_enable(RCC_CRS);
  crs_autotrim_usb_enable();
  rcc_set_usbclk_source(RCC_HSI48);
#else
  rcc_clock_setup_in_hse_8mhz_out_72mhz();
#endif /* STM32F0 */
#endif /* GD32F103 */

  rcc_periph_clock_enable(RCC_GPIOA); /* For USB */

/* STM32F0x2 has internal pullup and does not need AFIO */
#ifndef STM32F0
  rcc_periph_clock_enable(BOARD_RCC_USB_PULLUP);
  rcc_periph_clock_enable(RCC_AFIO); /* For SPI */
#endif /* STM32F0 */

#if BOARD_USE_DEBUG_PINS_AS_GPIO
  gpio_primary_remap(AFIO_MAPR_SWJ_CFG_JTAG_OFF_SW_OFF, AFIO_MAPR_TIM2_REMAP_FULL_REMAP);
#endif

/* Setup GPIO to pull up the D+ high. (STM32F0x2 has internal pullup.) */
#ifndef STM32F0
  gpio_set_mode(BOARD_PORT_USB_PULLUP, GPIO_MODE_OUTPUT_2_MHZ, GPIO_CNF_OUTPUT_PUSHPULL, BOARD_PIN_USB_PULLUP);
#if BOARD_USB_HIGH_IS_PULLUP
  gpio_set(BOARD_PORT_USB_PULLUP, BOARD_PIN_USB_PULLUP);
#else
  gpio_clear(BOARD_PORT_USB_PULLUP, BOARD_PIN_USB_PULLUP);
#endif /* BOARD_USB_HIGH_IS_PULLUP */
#endif /* STM32F0 */

  usbcdc_init();
#ifdef HAS_BOARD_INIT
  board_init();
#endif

  spi_setup(SPI_DEFAULT_CLOCK);

  /* The loop. */
  while (true) {
    /* Wait and blink if USB is not ready. */
    LED_IDLE();
    while (!usb_ready) {
      LED_DISABLE();
      for (i = 0; i < rcc_ahb_frequency / 150; i ++) {
        asm("nop");
      }
      LED_ENABLE();
      for (i = 0; i < rcc_ahb_frequency / 150; i ++) {
        asm("nop");
      }
    }

    /* Actual thing */
    /* TODO: we are blocked here, hence no knowledge about USB bet reset. */
    handle_command(usbcdc_getc());
  }

  return 0;
}

/* Interrupts (currently none here) */

static void signal_fault(void) {
  uint32_t i;

  while (true) {
    LED_ENABLE();
    LED_BUSY();
    for (i = 0; i < 5000000; i ++) {
      asm("nop");
    }
    LED_DISABLE();
    for (i = 0; i < 5000000; i ++) {
      asm("nop");
    }
  }
}

void nmi_handler(void)
__attribute__ ((alias ("signal_fault")));

void hard_fault_handler(void)
__attribute__ ((alias ("signal_fault")));

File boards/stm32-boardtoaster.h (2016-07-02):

#ifndef __BOARD_H__
#define __BOARD_H__

#include <stdbool.h>
#include <libopencm3/stm32/rcc.h>
#include <libopencm3/stm32/gpio.h>

/*
 * Board definitions for STM32 Board Toast
 * This is my spare-time project. It is a bread-board friendly minimal system for STM32F0x2.
 * There are also some derivatives on OSHPark. Eagle file will be released upon request.
 * OSHPark:
 *      https://oshpark.com/shared_projects/HUtPmtCZ
 */

#define BOARD_USE_DEBUG_PINS_AS_GPIO false

#define BOARD_RCC_LED                RCC_GPIOB
#define BOARD_PORT_LED               GPIOB
#define BOARD_PIN_LED                GPIO1
#define BOARD_LED_HIGH_IS_BUSY       true

/* STM32F0x2 has internal USB pullup. */

/* Currently you can only use SPI1, since it has highest clock. */

#endif /* __BOARD_H__ */

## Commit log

2015-11-29 added hardware files
    [main.brd, main.sch]
2015-12-26 debug for direct-mode DMA read finished
2015-12-26 debug for direct-mode DMA write finished
2015-12-26 switch to GPLv3
2015-12-28 multi-board support
2015-12-28 added pcb version 3
    [main.brd, main.sch]
2016-01-23 more testing on GD32, SPI not working
    [spi.c, vserprog.c]
2016-02-28 preliminary support for stm32f0x2. dma / spi is not working yet.
    [spi.c, spi.h, stm32-boardtoaster.h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]
2016-03-03 rename stm32-tiny042-v1 to stm32-tiny042 since 2 versions are equivalent
2016-03-03 SPI on STM32F0 fixed and tested
    [spi.c]
2016-07-02 Add support for 2 cheap ($2) STM32 Dev. boards called blue pill and red pill Since red one is no more manufactured or sold, board support name is stm32-bluepill You can build it with: make BOARD=stm3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
2016-07-02 add more information in board definitions, along with small fixes.
    [maple-mini.h, stm32-bluepill.h, stm32-boardtoaster.h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]
2016-09-17 make flashrom follow the staging branch
    Apparently the flashrom repo receives some heavy refactoring.
    Building stm32-vserprog with the stable branch of flashrom doesn't work anymore, thus the change to staging.
2017-04-25 add parameters in sch
    [main.brd, main.sch]
2017-05-23 remove prebuilt version since it does not make sense under new board selection system
2017-06-26 switch to official flashrom git
2018-01-10 Update all submodules also switch flashrom remote to official repo and update to v1.0 stable tag while we are at it.
2018-07-23 Add support for a cheap (~￥20) STM32 Dev. board The board is called JZ-01 V2.0, and can be bought from https://detail.tmall.com/item.htm?id=554703784397 , from which an RAR package containing schemat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
2018-07-23 split flash targets. In the future, board.mk will aliase flash to the correct target.
2018-09-12 Fix build warnings for unused functions
    [spi.c]
2018-11-09 fix oe for stm32f0
    [spi.c]
2019-10-05 Add support for XTW100 flash programmer
    It's not functioning correctly yet. The USB device can be found in the
    OS, and the LED is on when running flashrom. However, it can only read
    a W25Q32.V correctly on the first run after the programmer plugs in,
    and cannot erase/write.
2021-04-18 switch flashrom git url to mirror on GitHub
    The origin git host has moved to `https://review.coreboot.org/flashrom.git` .
    Officially mirrored on GitHub.
2021-10-13 Fix SPI baudrate for STM32F0 targets rcc.h provides a define for rcc_apb2_frequency which then collided with the local variable. As a result the SPI frequency was always 24MHz, no matter of the desir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
    [spi.c]
2021-10-13 Add definitions for an alternate board with a STM32F042
2022-07-28 Add support for a bluepill clone with the status LED inversed.
